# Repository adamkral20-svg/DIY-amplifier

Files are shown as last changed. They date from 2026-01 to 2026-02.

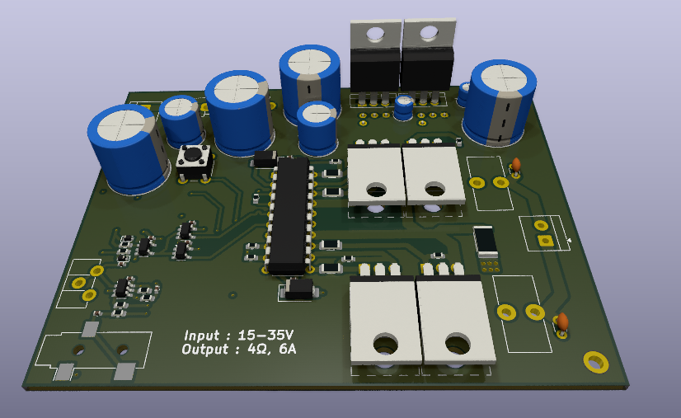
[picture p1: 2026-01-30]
assets/3D file.png

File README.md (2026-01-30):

# DIY-amplifier
Custom class-d amplifier board.
I made this since i previously tested a smaller version and i love loud music.
The project uses an oscillator design based on the schematic of [SineLab](https://www.youtube.com/@SineLab). I did change a few things to fit my design better.


This board is a Class - D audio amplifier with analog input(3.5mm audio jack) and gain setting.
It can work with 4-16 ohm speaker on output, and supply voltage < 35V. has OCP latch and a glass fuse.

It uses 4 MOSFETS in an H-bridge configuration, allowing for BTL output and thus higher power from lower supply voltage. 
The main part is the HIP-4081A H-bridge MOSFET gate driver. It can reliably drive the MOSFETS in the hundreds of kHz switching speed.


The onboard discrete oscillator should be around 200kHz.
It uses a pnp constant current source connected to a capacitor, and a MOSFET to discharge the capacitor quickly to generate a Ramp wave.
The MOSFET has 0.7nC gate charge, so the TLV3501 can reliably drive it with its output current capability.



The design by Sine lab


The overcurrent protection shuts off all MOSFETS when triggered, and keeps them off until the button is pressed. 
It uses an npn-pnp SCR based design to output a constant signal with a single pulse.


The pwm modulation is made possible by the MCP6561 comparator. 


To keep voltage levels for the audio and ramp wave similar, I'm using a 2V DC bias on audio, since the ramp wave is 0-4V


The logic circuits are powered by 7812 and 7805 repectively. 
I used many caps between VCC and GND to keep noise low from the H-bridge


# PCB layers
It uses 4 layers, since wiring it up with 2 layers, and still handling enough current was impossible, so i changed it to 4 to fit into < 100mm x 100mm size and handle ~5A on the output.

# Layer 1(Vcc)


# Layer 2(5V)


# Layer 3(12V)


# Layer 4(GND)


# Credits

- [KiCad](https://www.kicad.org/)
- [Fusion 360](https://www.autodesk.com/products/fusion-360/overview)
- [Blueprint project](https://blueprint.hackclub.com/projects/10381)

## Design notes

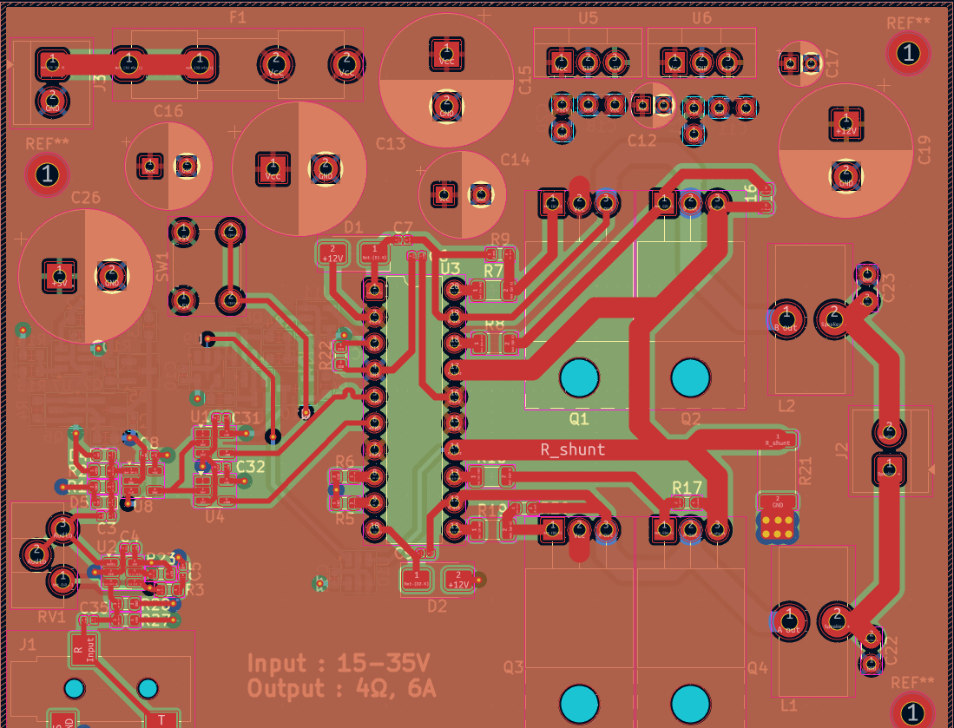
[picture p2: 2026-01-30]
assets/Layer 1.png

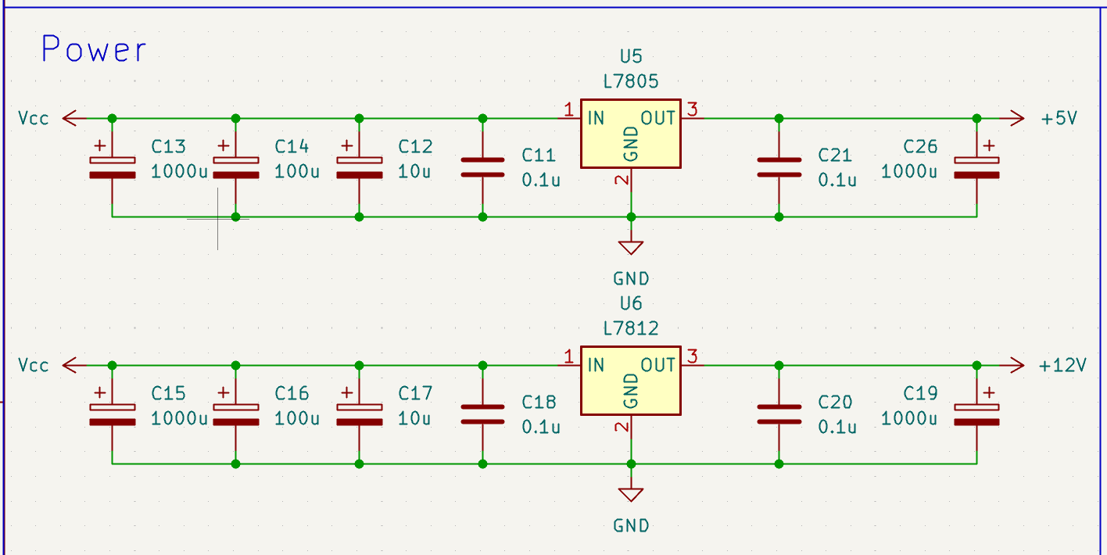
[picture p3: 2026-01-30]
assets/Power.png

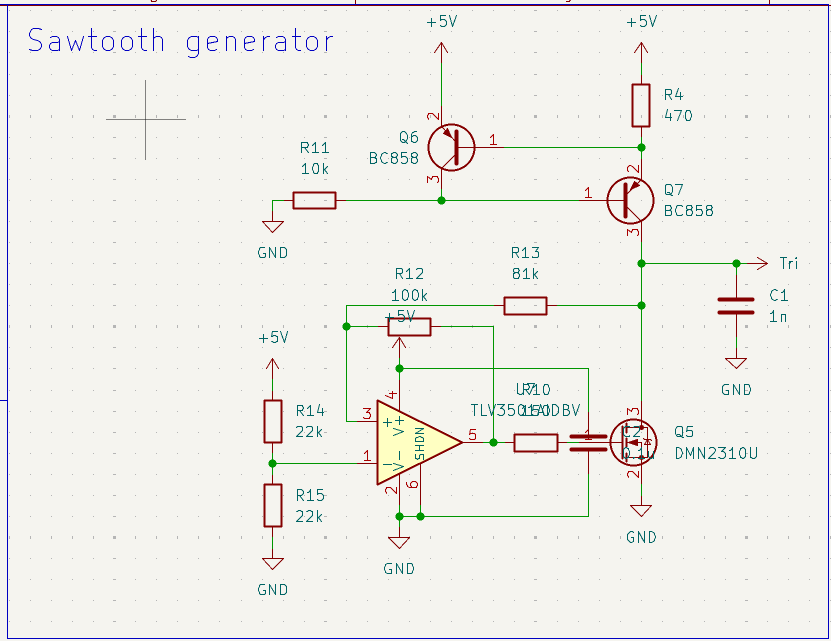
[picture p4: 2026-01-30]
assets/Saw_gen.png

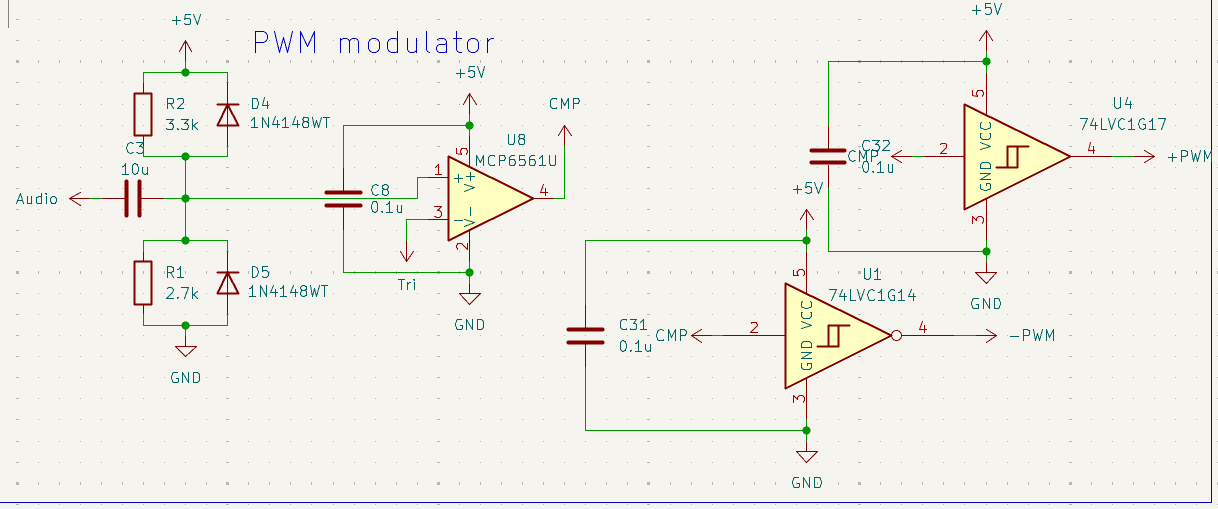
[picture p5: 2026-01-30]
assets/PWM modulator.png

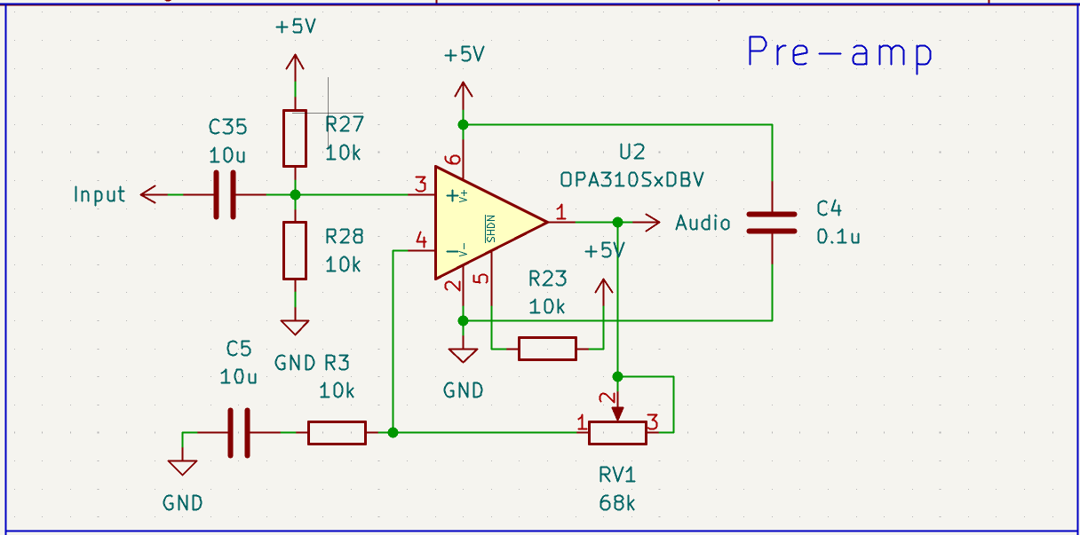
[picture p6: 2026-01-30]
assets/Pre-amp.png

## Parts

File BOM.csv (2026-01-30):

Reference | Value | Footprint | Datasheet | Qty | Part | Price
C1 | 1n | Capacitor_SMD:C_0402_1005Metric | ~ | 1 | DigiKey | 0,10 €
C2,C4,C6,C7,C8,C9,C10,C24,C31,C32,C33 | 0.1u | Capacitor_SMD:C_0402_1005Metric | ~ | 11 | DigiKey | 0,02 €
C3,C5,C35 | 10u | Capacitor_SMD:C_0402_1005Metric | ~ | 3 | DigiKey | 0,24 €
C11,C18,C20,C21 | 0.1u | Capacitor_THT:C_Disc_D3.0mm_W1.6mm_P2.50mm | ~ | 4 | DigiKey | 1,04 €
C12,C17 | 10u | Capacitor_THT:CP_Radial_D4.0mm_P2.00mm | ~ | 2 | DigiKey | 0,22 €
C13,C15,C19,C26 | 1000u | Capacitor_THT:CP_Radial_D8.0mm_P2.50mm | ~ | 4 | DigiKey | 4,36 €
C14,C16 | 100u | Capacitor_THT:CP_Radial_D6.3mm_P2.50mm | ~ | 2 | DigiKey | 0,70 €
C22,C23 | 1.5u | Capacitor_THT:C_Disc_D3.0mm_W1.6mm_P2.50mm | ~ | 2 | DigiKey | 1,46 €
D1,D2 | CDBA3100-HF | Diode_SMD:D_SMA | https://www.comchiptech.com/admin/files/product/CDBA340-HF%20Thru193640.%20CDBA3100-HF%20RevB.pdf | 2 | DigiKey | 1,50 €
D4,D5 | 1N4148WT | Diode_SMD:D_SOD-523 | https://www.diodes.com/assets/Datasheets/ds30396.pdf | 2 | DigiKey | 0,20 €
F1 | 6A | Fuse:Fuseholder_Clip-5x20mm_Eaton_1A5601-01_Inline_P20.80x6.76mm_D1.70mm_Horizontal | ~ | 1 | DigiKey | 1,70 €
J1 | AudioPlug3 | Connector_Audio:Jack_3.5mm_CUI_SJ-3523-SMT_Horizontal | ~ | 1 | DigiKey | 0,86 €
J2 | Output | TerminalBlock_4Ucon:TerminalBlock_4Ucon_1x02_P3.50mm_Horizontal | ~ | 1 | DigiKey | 0,62 €
J3 | Input | TerminalBlock_4Ucon:TerminalBlock_4Ucon_1x02_P3.50mm_Horizontal | ~ | 1 | DigiKey | 0,62 €
L1,L2 | 47u | Inductor_THT:L_Toroid_Vertical_L14.0mm_W6.3mm_P4.57mm_Pulse_A | ~ | 2 | Mouser | 3,48 €
Q1,Q2,Q3,Q4 | IRF540N | Package_TO_SOT_THT:TO-220-3_Horizontal_TabUp | http://www.irf.com/product-info/datasheets/data/irf540n.pdf | 4 | Mouser | 2,13 €
Q5 | DMN2310U | Package_TO_SOT_SMD:SOT-23 | http://www.diodes.com/assets/Datasheets/ds31180.pdf | 1 | DigiKey | 0,20 €
Q6,Q7,Q9 | BC858 | Package_TO_SOT_SMD:SOT-23 | https://www.onsemi.com/pub/Collateral/BC860-D.pdf | 3 | DigiKey | 0,51 €
Q8 | BC848 | Package_TO_SOT_SMD:SOT-23 | http://www.infineon.com/dgdl/Infineon-BC847SERIES_BC848SERIES_BC849SERIES_BC850SERIES-DS-v01_01-en.pdf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 | 1 | DigiKey | 0,11 €
Q10 | PJA3431 | Package_TO_SOT_SMD:SOT-23-3 | https://ngspice.sourceforge.io/docs/ngspice-html-manual/manual.xhtml#cha_MOSFETs | 1 | DigiKey | 0,27 €
R1 | 2.7k | Resistor_SMD:R_0603_1608Metric | ~ | 1 | DigiKey | 0,10 €
R2 | 3.3k | Resistor_SMD:R_0603_1608Metric | ~ | 1 | DigiKey | 0,10 €
R3,R9,R11,R16,R17,R20,R22,R23,R24,R26,R27,R28,R30 | 10k | Resistor_SMD:R_0603_1608Metric | ~ | 13 | DigiKey | 0,39 €
R4,R25 | 470 | Resistor_SMD:R_0603_1608Metric | ~ | 2 | DigiKey | 0,20 €
R5,R6 | 220k | Resistor_SMD:R_0603_1608Metric | ~ | 2 | DigiKey | 0,20 €
R7,R8,R18,R19 | 10 | Resistor_SMD:R_1206_3216Metric | ~ | 4 | DigiKey | 0,40 €
R10 | 150 | Resistor_SMD:R_0603_1608Metric | ~ | 1 | DigiKey | 0,10 €
R12 | 100k | Resistor_SMD:R_0603_1608Metric | ~ | 1 | DigiKey | 0,10 €
R13 | 81k | Resistor_SMD:R_0603_1608Metric | ~ | 1 | DigiKey | 0,10 €
R14,R15 | 22k | Resistor_SMD:R_0603_1608Metric | ~ | 2 | DigiKey | 0,20 €
R21 | 0.03 | Resistor_SMD:R_2512_6332Metric | ~ | 1 | DigiKey | 0,55 €
RV1 | 68k | Potentiometer_THT:Potentiometer_ACP_CA9-H2,5_Horizontal | ~ | 1 | DigiKey | 2,05 €
SW1 | SW_Push | Button_Switch_THT:SW_PUSH_6mm | ~ | 1 | DigiKey | 0,21 €
U1,U11 | 74LVC1G14 | Package_TO_SOT_SMD:SOT-23-5 | https://www.ti.com/lit/sg/scyt129e/scyt129e.pdf | 2 | DigiKey | 0,24 €
U2 | OPA310SxDBV | Package_TO_SOT_SMD:SOT-23-6 | https://www.ti.com/lit/ds/symlink/opa310.pdf | 1 | DigiKey | 0,85 €
U3 | HIP4081A | Package_DIP:DIP-20_W7.62mm | http://www.intersil.com/content/dam/Intersil/documents/hip4/hip4080a.pdf | 1 | DigiKey | 7,18 €
U4,U9 | 74LVC1G17 | Package_TO_SOT_SMD:SOT-23-5 | https://www.ti.com/lit/ds/symlink/sn74lvc1g17.pdf | 2 | DigiKey | 0,30 €
U5 | L7805 | Package_TO_SOT_THT:TO-220-3_Vertical | http://www.st.com/content/ccc/resource/technical/document/datasheet/41/4f/b3/b0/12/d4/47/88/CD00000444.pdf/files/CD00000444.pdf/jcr:content/translations/en.CD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 | 1 | DigiKey | 0,52 €
U6 | L7812 | Package_TO_SOT_THT:TO-220-3_Vertical | http://www.st.com/content/ccc/resource/technical/document/datasheet/41/4f/b3/b0/12/d4/47/88/CD00000444.pdf/files/CD00000444.pdf/jcr:content/translations/en.CD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 | 1 | DigiKey | 0,52 €
U7 | TLV3501AIDBV | Package_TO_SOT_SMD:SOT-23-6 | https://www.ti.com/lit/ds/symlink/tlv3501.pdf | 1 | DigiKey | 3,51 €
U8 | MCP6561U | Package_TO_SOT_SMD:SOT-23-5 | http://ww1.microchip.com/downloads/en/DeviceDoc/MCP6561-1R-1U-2-4-1.8V-Low-Power-Push-Pull-Output-Comparator-DS20002139E.pdf | 1 | DigiKey | 0,55 €
U10 | INA181 | Package_TO_SOT_SMD:SOT-23-6 | http://www.ti.com/lit/ds/symlink/ina181.pdf | 1 | DigiKey | 0,43 €
 |  |  |  |  |  | 39,14 €

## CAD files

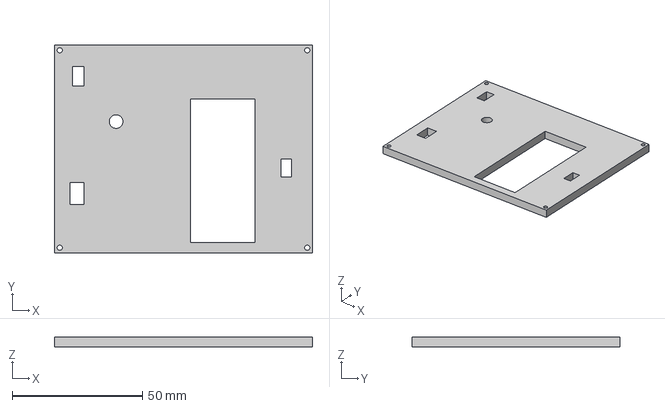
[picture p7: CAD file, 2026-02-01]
CAD files/Top_side.3mf
98.9 x 79.6 x 4.00 mm

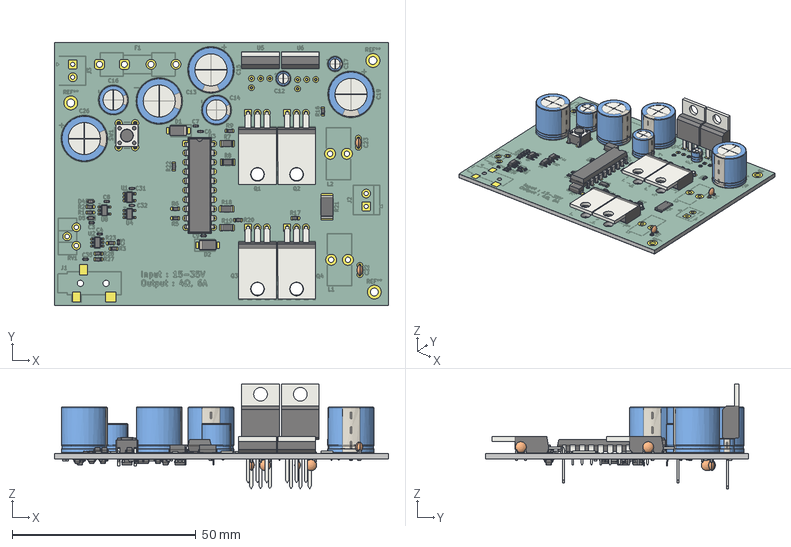
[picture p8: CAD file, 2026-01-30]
CAD files/DIY amplifier.step
90.9 x 71.6 x 28.5 mm
TO-220-3_Horizontal_TabUp x 4
C_Disc_D3.0mm_W1.6mm_P2.50mm x 6
R_1206_3216Metric x 4
SOT-23-5 x 5
C_0402_1005Metric x 15
R_0603_1608Metric x 24
R_2512_6332Metric
CP_Radial_D12.5mm_P5.00mm x 4
CP_Radial_D8.0mm_P3.50mm x 2
TO-220-3_Vertical x 2
D_SMA x 2
CP_Radial_D4.0mm_P2.00mm x 2
SOT-23-6 x 3
DIP-20_W7.62mm
SW_PUSH_6mm
D_SOD-523 x 2
SOT-23 x 5
SOT-23-3
DIY amplifier_copper
DIY amplifier_silkscreen x 2
DIY amplifier_soldermask x 2
DIY amplifier_PCB

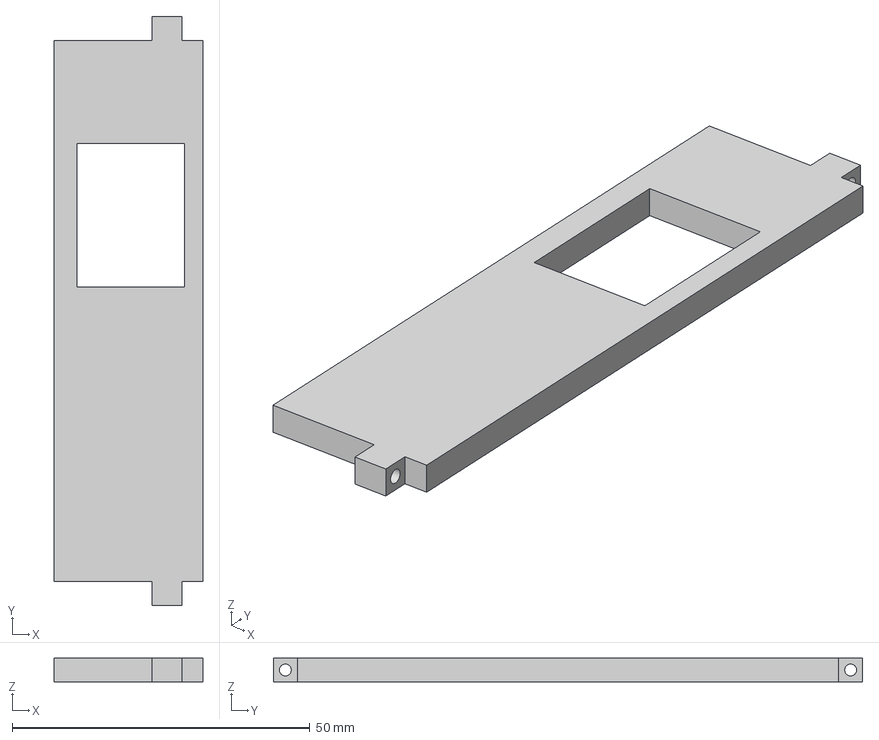
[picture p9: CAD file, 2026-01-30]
CAD files/Front_side.3mf
25.0 x 98.8 x 4.00 mm

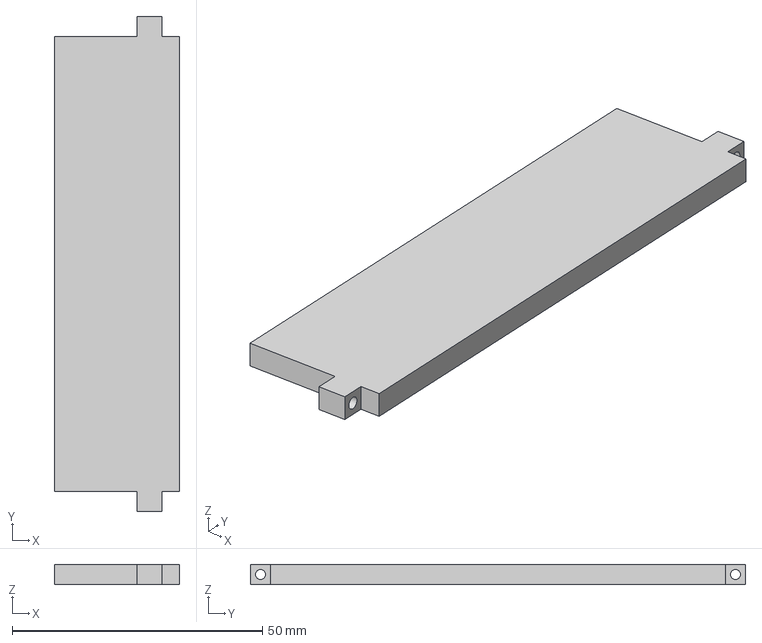
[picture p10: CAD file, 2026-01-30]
CAD files/Back_side.3mf
25.0 x 98.8 x 4.00 mm

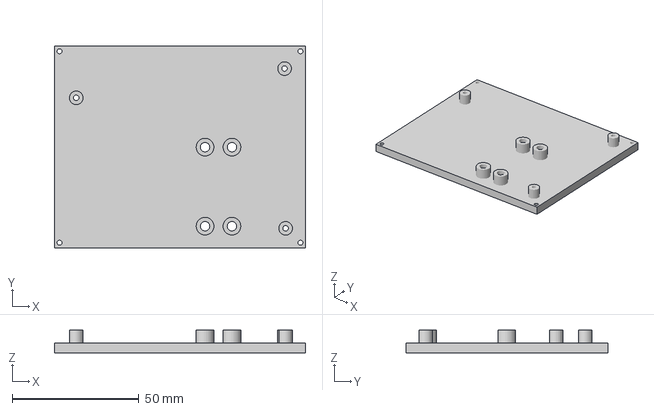
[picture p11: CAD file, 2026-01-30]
CAD files/Bottom_side.3mf
99.0 x 79.5 x 9.00 mm

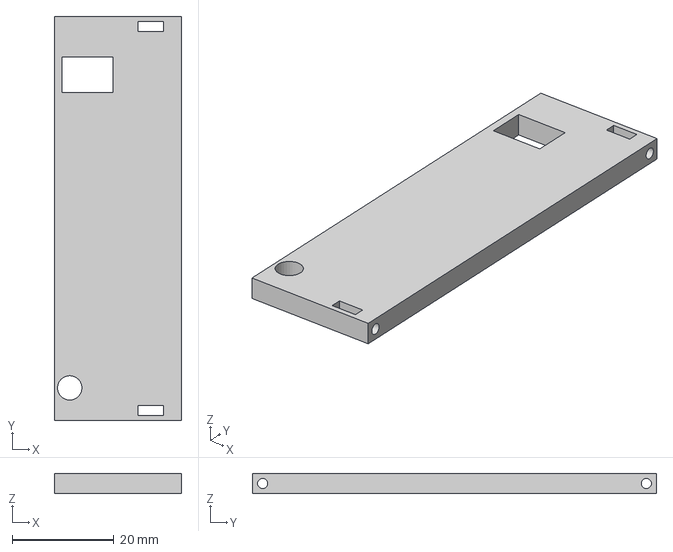
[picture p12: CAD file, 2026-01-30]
CAD files/Left_side.3mf
25.0 x 79.5 x 4.00 mm

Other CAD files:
CAD files/Right_side.3mf

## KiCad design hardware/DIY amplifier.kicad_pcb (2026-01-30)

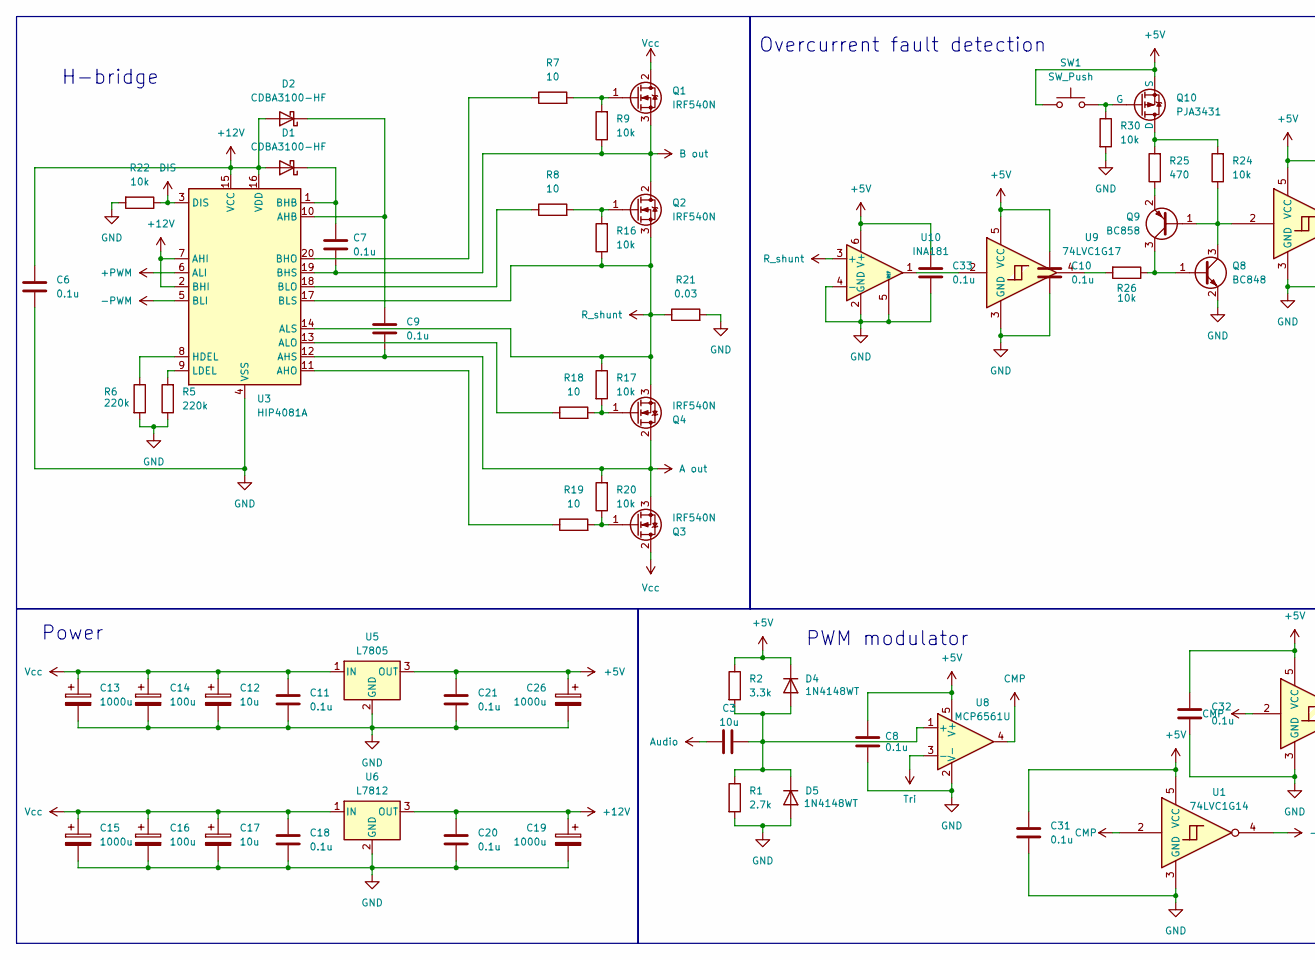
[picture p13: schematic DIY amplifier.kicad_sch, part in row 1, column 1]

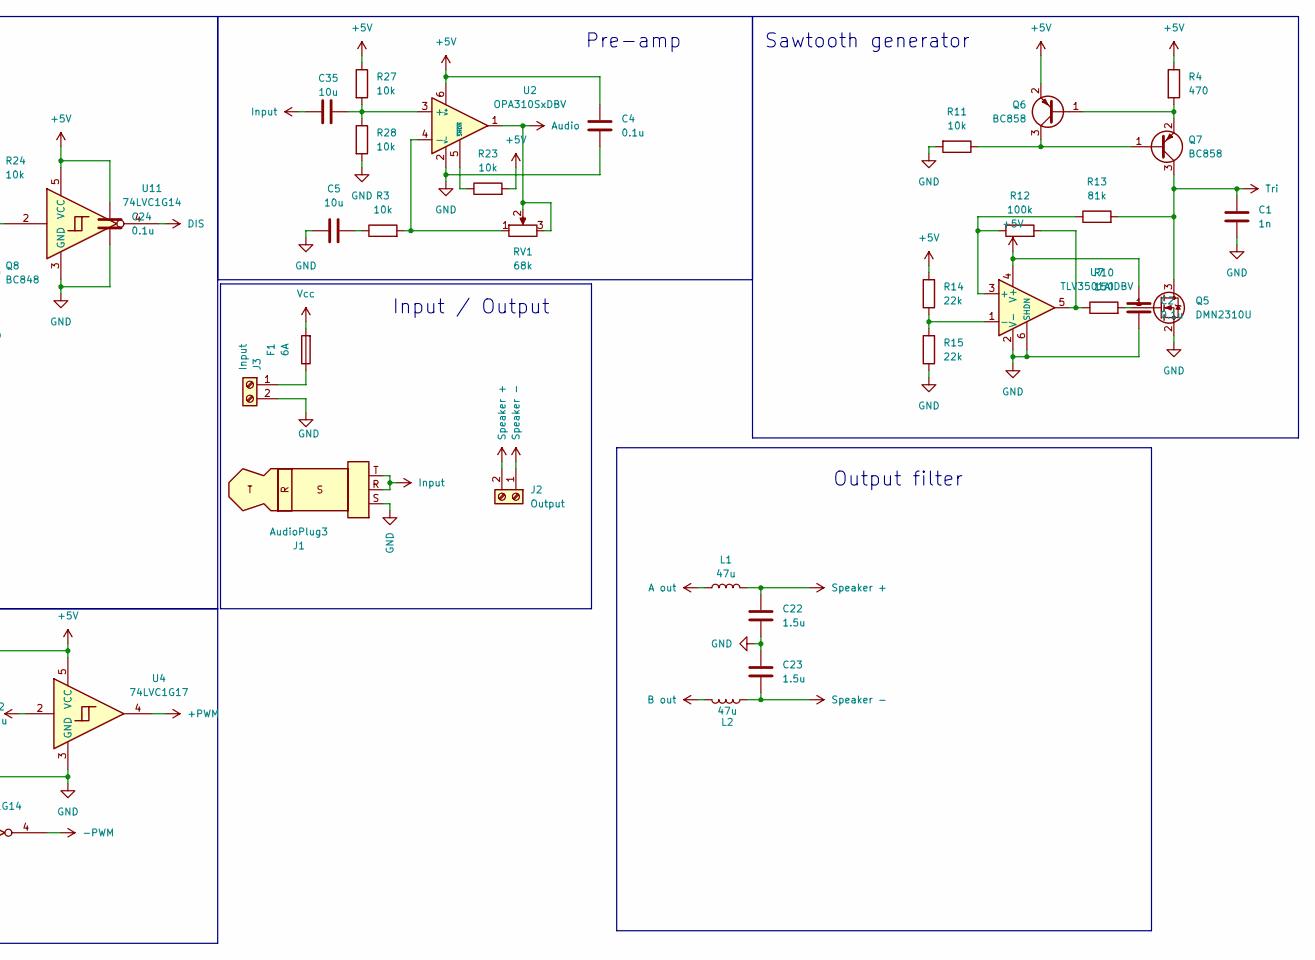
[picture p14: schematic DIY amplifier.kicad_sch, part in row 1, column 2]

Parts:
C1: 1n; C_0402_1005Metric
C2, C4, C6, C7, C8, C9, C10, C24, C31, C32, C33: 0.1u; C_0402_1005Metric
C3, C5, C35: 10u; C_0402_1005Metric
C11, C18, C20, C21: 0.1u; C_Disc_D3.0mm_W1.6mm_P2.50mm
C12, C17: 10u; CP_Radial_D4.0mm_P2.00mm
C13, C15, C19, C26: 1000u; CP_Radial_D12.5mm_P5.00mm
C14, C16: 100u; CP_Radial_D8.0mm_P3.50mm
C22, C23: 1.5u; C_Disc_D3.0mm_W1.6mm_P2.50mm
D1, D2: CDBA3100-HF; D_SMA
D4, D5: 1N4148WT; D_SOD-523
F1: 6A; Fuseholder_Clip-5x20mm_Eaton_1A5601-01_Inline_P20.80x6.76mm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
J1: AudioPlug3; Jack_3.5mm_CUI_SJ-3523-SMT_Horizontal
J2: Output; TerminalBlock_4Ucon_1x02_P3.50mm_Horizontal
J3: Input; TerminalBlock_4Ucon_1x02_P3.50mm_Horizontal
L1, L2: 47u; L_Toroid_Vertical_L14.0mm_W6.3mm_P4.57mm_Pulse_A
Q1, Q2, Q3, Q4: IRF540N; TO-220-3_Horizontal_TabUp
Q5: DMN2310U; SOT-23
Q6, Q7, Q9: BC858; SOT-23
Q8: BC848; SOT-23
Q10: PJA3431; SOT-23-3
R1: 2.7k; R_0603_1608Metric
R2: 3.3k; R_0603_1608Metric
R3, R9, R11, R16, R17, R20, R22, R23, R24, R26, R27, R28, R30: 10k; R_0603_1608Metric
R4, R25: 470; R_0603_1608Metric
R5, R6: 220k; R_0603_1608Metric
R7, R8, R18, R19: 10; R_1206_3216Metric
R10: 150; R_0603_1608Metric
R12: 100k; R_0603_1608Metric
R13: 81k; R_0603_1608Metric
R14, R15: 22k; R_0603_1608Metric
R21: 0.03; R_2512_6332Metric
RV1: 68k; Potentiometer_ACP_CA9-H2,5_Horizontal
SW1: SW_Push; SW_PUSH_6mm_H13mm
U1, U11: 74LVC1G14; SOT-23-5
U2: OPA310SxDBV; SOT-23-6
U3: HIP4081A; DIP-20_W7.62mm
U4, U9: 74LVC1G17; SOT-23-5
U5: L7805; TO-220-3_Vertical
U6: L7812; TO-220-3_Vertical
U7: TLV3501AIDBV; SOT-23-6
U8: MCP6561U; SOT-23-5
U10: INA181; SOT-23-6

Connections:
+5V: C2.1, C4.1, C8.1, C10.1, C21.2, C24.1, C26.1, C31.1, C32.1, C33.1, D4.1 (K), Q6.2 (E), Q10.3 (S), R2.1, R4.1, R14.2, R23.2, R27.1, SW1.1, U1.5 (VCC), U2.6 (V+), U4.5 (VCC), U5.3 (OUT), U7.4 (V+), U8.5 (V+), U9.5 (VCC), U10.6 (V+), U11.5 (VCC)
+12V: C6.1, C19.1, C20.2, D1.2 (A), D2.2 (A), U3.2 (BHI), U3.7 (AHI), U3.15 (VCC), U3.16 (VDD), U6.3 (OUT)
+PWM: U3.6 (ALI), U4.4
-PWM: U1.4, U3.5 (BLI)
A out: C9.2, L1.1, Q3.3 (S), Q4.2 (D), R20.2, U3.12 (AHS)
Audio: C3.1, RV1.2, RV1.3, U2.1
B out: C7.2, L2.1, Q1.3 (S), Q2.2 (D), R9.1, U3.19 (BHS)
CMP: U1.2, U4.2, U8.4
DIS: R22.1, U3.3 (DIS), U11.4
GND: C1.2, C2.2, C4.2, C5.1, C6.2, C8.2, C10.2, C11.1, C12.2, C13.2, C14.2, C15.2, C16.2, C17.2, C18.1, C19.2, C20.1, C21.1, C22.1, C23.1, C24.2, C26.2, C31.2, C32.2, C33.2, D5.2 (A), J1.S, J3.2, Q5.2 (S), Q8.2 (E), R1.2, R5.1, R6.2, R11.2, R15.1, R21.2, R22.2, R28.2, R30.2, U1.3 (GND), U2.2 (V-), U3.4 (VSS), U4.3 (GND), U5.2 (GND), U6.2 (GND), U7.2 (V-), U7.6 (SHDN), U8.2 (V-), U9.3 (GND), U10.2 (GND), U10.4 (-), U10.5 (REF), U11.3 (GND)
Input: C35.1, J1.R, J1.T
unnamed: C5.2, R3.1
unnamed: C7.1, D1.1 (K), U3.1 (BHB)
unnamed: C9.1, D2.1 (K), U3.10 (AHB)
unnamed: C3.2, D4.2 (A), D5.1 (K), R1.1, R2.2, U8.1 (+)
unnamed: F1.1, J3.1
unnamed: Q1.1 (G), R7.2, R9.2
unnamed: Q2.1 (G), R8.2, R16.2
unnamed: Q3.1 (G), R19.2, R20.1
unnamed: Q4.1 (G), R17.2, R18.2
unnamed: Q5.1 (G), R10.2
unnamed: Q6.1 (B), Q7.2 (E), R4.2
unnamed: Q6.3 (C), Q7.1 (B), R11.1
unnamed: Q8.1 (B), Q9.3 (C), R26.1
unnamed: Q8.3 (C), Q9.1 (B), R24.1, U11.2
unnamed: Q9.2 (E), R25.1
unnamed: Q10.1 (D), R24.2, R25.2
unnamed: Q10.2 (G), R30.1, SW1.2
unnamed: R10.1, R12.2, U7.5
unnamed: R26.2, U9.4
unnamed: C35.2, R27.2, R28.1, U2.3 (+)
unnamed: R3.2, RV1.1, U2.4 (-)
unnamed: R23.1, U2.5 (~SHDN)
unnamed: R19.1, U3.11 (AHO)
unnamed: R18.1, U3.13 (ALO)
unnamed: R7.1, U3.20 (BHO)
unnamed: R8.1, U3.18 (BLO)
unnamed: R6.1, U3.8 (HDEL)
unnamed: R5.2, U3.9 (LDEL)
unnamed: R12.1, R13.1, U7.3 (+)
unnamed: R14.1, R15.2, U7.1 (-)
unnamed: U9.2, U10.1
R_shunt: Q2.3 (S), Q4.3 (S), R16.1, R17.1, R21.1, U3.14 (ALS), U3.17 (BLS), U10.3 (+)
Tri: C1.1, Q5.3 (D), Q7.3 (C), R13.2, U8.3 (-)
Vcc: C11.2, C12.1, C13.1, C14.1, C15.1, C16.1, C17.1, C18.2, F1.2, Q1.2 (D), Q3.2 (D), U5.1 (IN), U6.1 (IN)

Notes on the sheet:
H-bridge
Sawtooth generator
Overcurrent fault detection
PWM modulator
Pre-amp
Power
Output filter
Input / Output

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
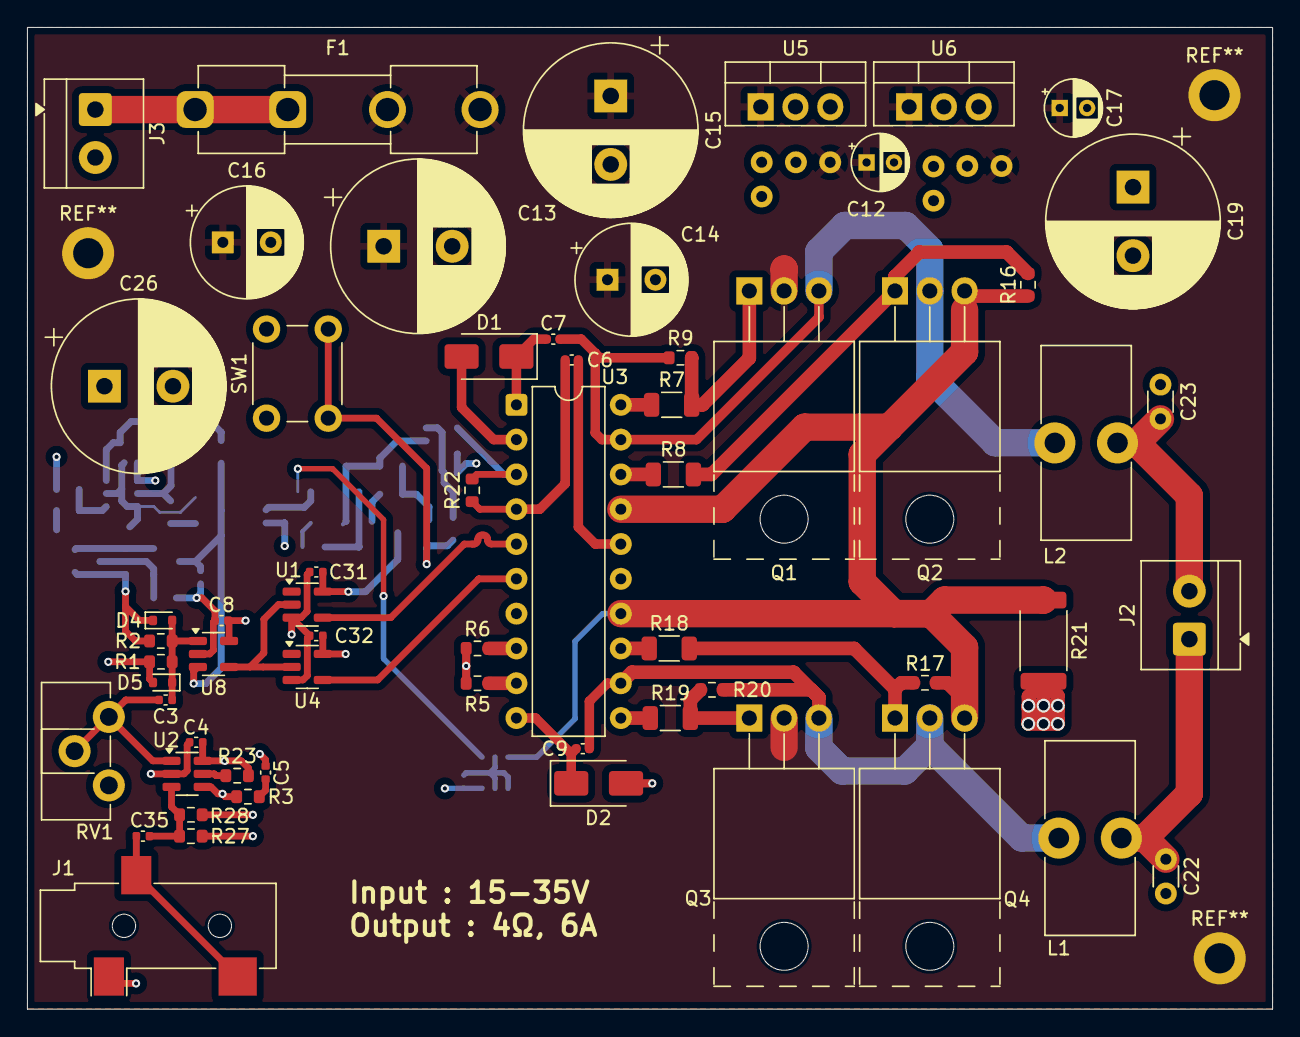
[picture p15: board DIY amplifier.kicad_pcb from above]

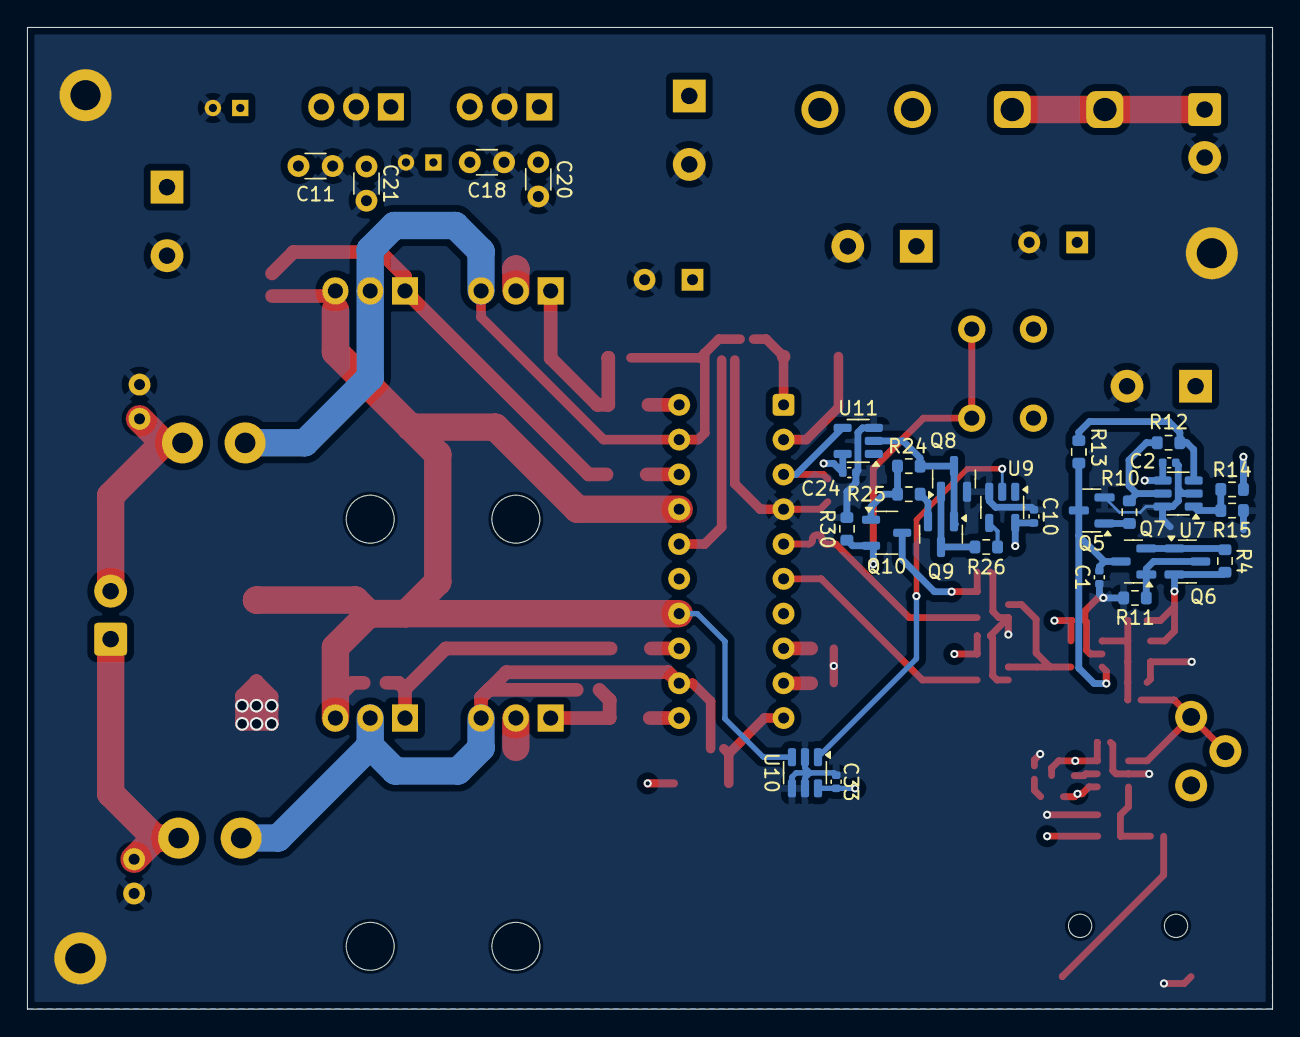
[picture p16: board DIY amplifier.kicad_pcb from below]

Board: 4 copper layers, 90.9 x 71.6 mm, 91 parts (30 on the bottom side), 47 nets.

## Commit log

2026-01-26 Rename folder for DIY amplifier PCB
2026-01-30 Enhance README with PCB layers and credits
    Added PCB layer details and credits section to README.
